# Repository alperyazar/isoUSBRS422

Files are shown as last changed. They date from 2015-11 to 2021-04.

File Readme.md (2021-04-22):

# isoUSBRS422

Links:

| | |
| --- |---|
| Up-to-date BOM (with price) | [https://octopart.com/bom-tool/p8YATXJo](https://octopart.com/bom-tool/p8YATXJo) |
| Known Issues | [https://github.com/alperyazar/isoUSBRS422/issues](https://github.com/alperyazar/isoUSBRS422/issues)
| Photo Gallery | [https://www.flickr.com/photos/134583834@N07/sets/72157658466808770/](https://www.flickr.com/photos/134583834@N07/sets/72157658466808770/) |
| Hackaday.io | [https://hackaday.io/project/3943-isousbrs422](https://hackaday.io/project/3943-isousbrs422) |
| Project Page on My Website (may contain additional materials) | [https://www.ayazar.com/projects/isousbrs422.html](https://www.ayazar.com/projects/isousbrs422.html) |

> :information_source: isoUSBRS422v1 is on **EEVblog Mailbag** and **Dangerous Prototypes.** See [On The Web](#on-the-web) section at the bottom for details.

isoUSBRS422 is an **isolated** USB <-> RS422/RS485 converter board (~5x5 cm). It should work with Windows, Linux and MacOSX (not fully tested for all operating systems by me).

**THIS PROJECT IS PUBLISHED UNDER CC BY-NC-SA 4.0 LICENSE**

**AS IS, ABSOLUTELY NO WARRANTY**

## Features

Here is the summary of features in “catalog” style:

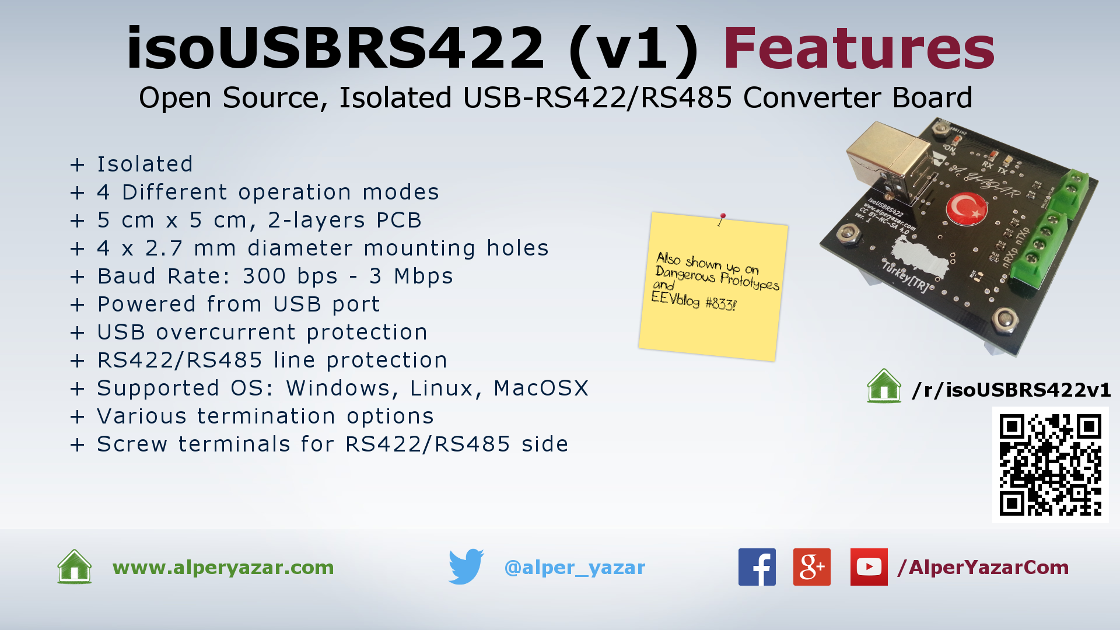
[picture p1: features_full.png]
Summary of isoUSBRS422 features


*Summary of isoUSBRS422 features*

Here is the introduction video:

Part 1 - Features | isoUSBRS422v1 (with Subtitles) (http://www.youtube.com/watch?v=jb3v3Kmv85k "Part 1 - Features | isoUSBRS422v1 (with Subtitles)")

* **Isolated** 5000 Vrms (IC specification, not tested by me)
* **4 different modes** RS-422, RS-485 4-wire, RS-485 2-wire, RS-485 2-wire w/echo suppression
* **5 cm x 5 cm, 2-layers PCB**
* **4 x 2.7 mm diameter mounting holes** Electrically floating
* **Baud Rate: 300 bps - 3 Mbps** Baud Rate = 3000000 / (n + x) where ‘n’ can be any integer between 2 and 16,384 and ‘x’ can be a sub-integer of the value 0, 0.125, 0.25, 0.375, 0.5, 0.625, 0.75, or 0.875. When n = 1, x = 0, i.e. baud rate divisors with values between 1 and 2 are not possible.
* **Powered from USB port** No external power supply is required. 5V from USB port is sufficient to operate the device.
* **USB overcurrent protection** Yes, by a polyfuse
* **RS-422/RS-485 line protection** Yes, it should meet IEC 61000-4-2, 61000-4-4 and IEC 61000-4-5 (IC specification, not tested by me)
* Supported OS: **Windows, Linux, MacOSX**
* **Various termination options** Different termination topologies can be selected by changing some passives on the component side using solder and iron! (Sorry, no dip switches)
* **Screw terminals for RS-422/RS-485 side**
* **LED indicators: Power, Transmit, Receive**

## What is isoUSBRS422?

As I said, basically it is an USB ↔ RS-422/RS-485 converter board. It can be used to communicate devices with RS-422/RS-485 interface by using a USB port of PC. Also, ground of USB port is isolated from ground of RS-422/RS-485 channel. It may help you to prevent [ground loops](https://en.wikipedia.org/wiki/Ground_loop_%28electricity%29) in large systems. See [Galvanic isolation](https://en.wikipedia.org/wiki/Galvanic_isolation) for further explanation. I will explain technical details later.

isoUSBRs422 is my first open source hardware and also KiCad experience. I did some boards for my daily job previously, but I never published them in public domain. So, I decided to do "something" to gain experience about open source publishing and low cost PCB production. Here there are some photos:

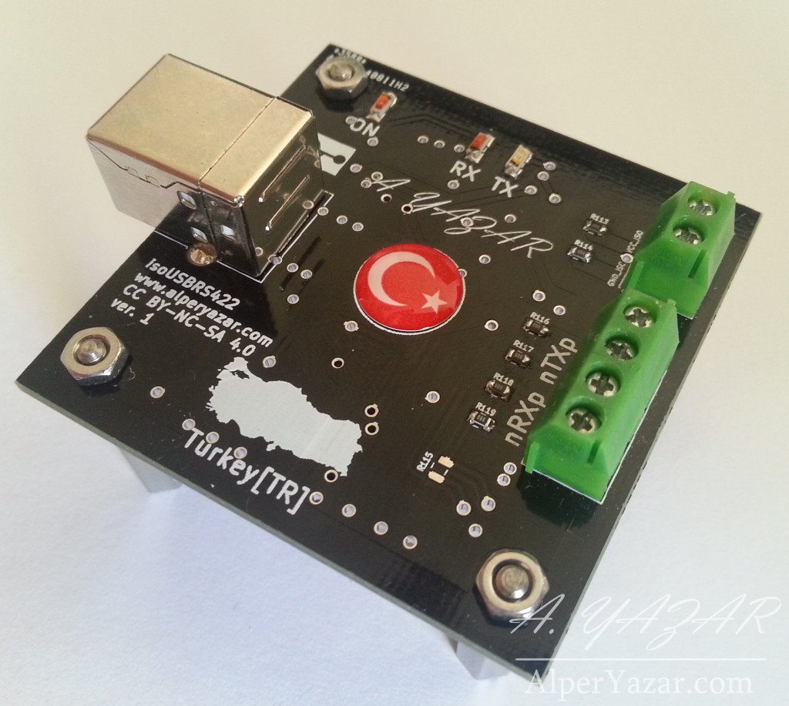
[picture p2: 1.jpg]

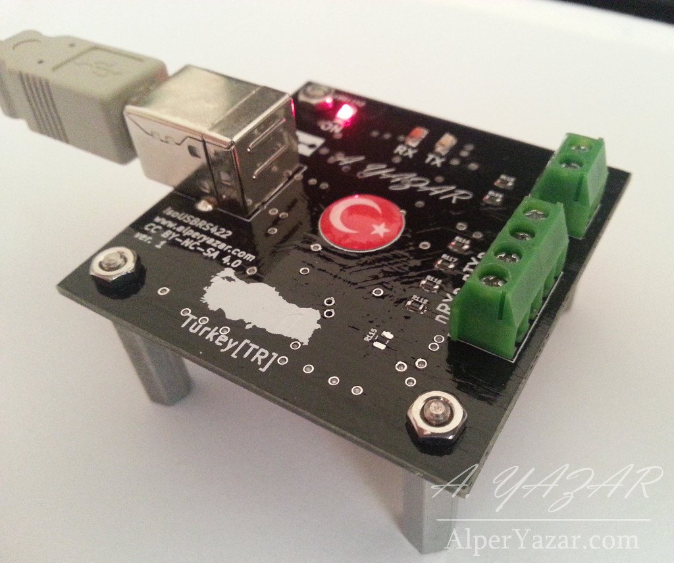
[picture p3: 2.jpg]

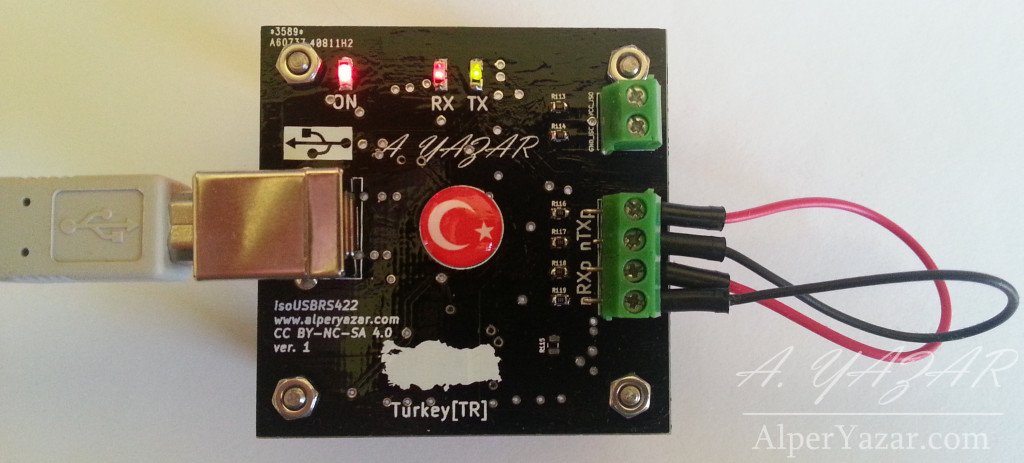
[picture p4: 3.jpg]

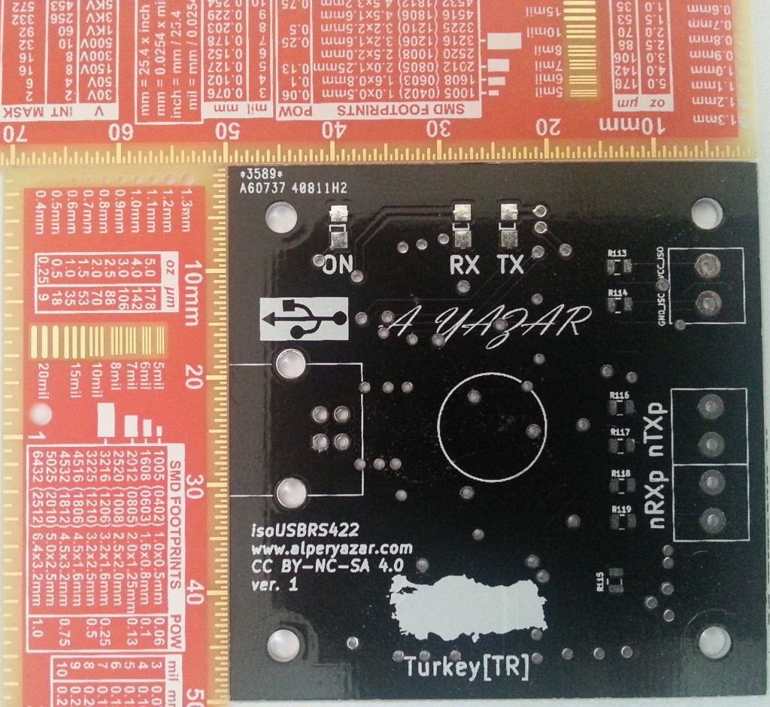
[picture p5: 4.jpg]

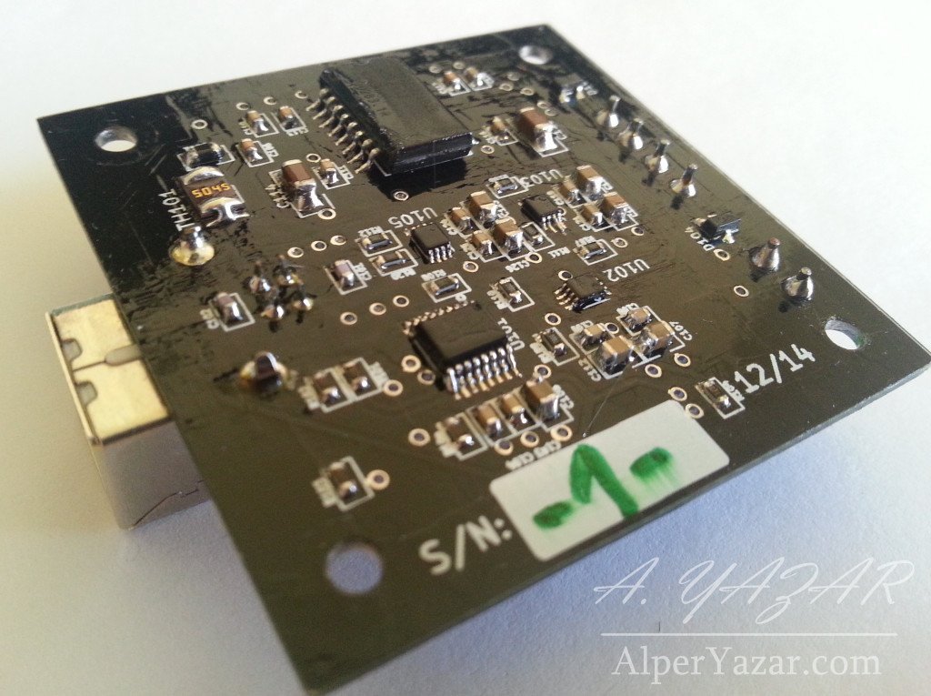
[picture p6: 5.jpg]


## Why

### Why did I design an isolated USB ↔ RS-422/RS-485 converter board?

As I explained previously, I wanted to design and publish "something". I use USB ↔ RS-422 converter devices for my daily job heavily. I checked PCB manufacturers and decided to try Dirtypcbs. Dimension limit for the cheapest option is 5 cm x 5 cm and I decided to stick to this limit. I thought that I can design an isolated USB <-> RS-422 converter board within in this size limit and use it for my daily job. So I did it.

### Why did I chose the name isoUSBRS422? Does this board support RS-485 in addition to RS-422, right?

Yes, it supports both protocols. My initial goal was designing an isolated USB ↔ RS-422 converter board. Because I use RS-422 mainly not RS-485. However after design I noticed that it can also be used as an RS-485 converter. Also a name like *isoUSBRS422-485* is quite long for a board name.

### Why did I use KiCad?

Couple of years ago, I designed 3 different boards for my project design course in collage using DipTrace. DipTrace is great and I would continue to use it if I didn’t decide to publish my project and make it open source. DipTrace has *freeware* version for non-commercial users. However, this version has limitation on number of total pins on a single PCB. I think that software used for an open source project should be free (as in beer and freedom) as much as possible. Also, I had to create some parts in library for this project. If I use DipTrace, later I may hit the pin limit for my other projects and I have to move another software. For these reasons, I eliminate Eagle. I think that, it is easier to learn and use DipTrace than Eagle.

From *free* PCB design softwares, I tried gEDA and KiCad. I encountered some stability issues in gEDA then I selected to use KiCad. This is my first KiCad and experience and now I am happy with my decision. I recommend KiCad. It has quite good documentation and there are great videos on YouTube explaining almost all aspects of the software. Also there are active helping forums on the internet.

### Why the heck did I select a USB chip from FTDI? Don’t I know that they did stupid things in the past? Am I supporting them?

Yes, I know and I am not an FTDI fanboy. For those who don’t know the subject:

EEVblog #676 - RANT: FTDI Bricking Counterfeit Chips! (http://www.youtube.com/watch?v=eU66as4Bbds "EEVblog #676 - RANT: FTDI Bricking Counterfeit Chips!")

and

[http://hackaday.com/2014/10/22/watch-that-windows-update-ftdi-drivers-are-killing-fake-chips/](http://hackaday.com/2014/10/22/watch-that-windows-update-ftdi-drivers-are-killing-fake-chips/)

started to desing and selected to components prior to FTDI thing. I learned the issue in the beginning of the layout. I was very excited to finish my board and decided to finish it. So, that’s the story. Now, I can’t proudly say that “Hey, I am using an FTDI chip on my board”. I know that, many of hackers and makers encountered problems due to stupidity of this company. Since this is an open source project and aims makers especially, I am not very happy with this chip. But this is the case.

## Do It Yourself (DIY)



> :warning: AS IS, ABSOLUTELY NO WARRANTY. TAKE YOUR OWN RISK

Your read the features list and are fascinated about the project (LOL). You look forward to make your own isoUSBRS422 board and use it in your projects. Here is the good new: This is an open source project and you can make your own copy for non-commercial purposes!

> :information_source: This project is published under CC BY-NC-SA 4.0 license. It means that you can make your own copy for non-commercial purposes. Even, you can modify the project files, ex. PCB, if you refer to this original work properly and redistribute your version with the same license. See [https://creativecommons.org/licenses/by-nc-sa/4.0/](https://creativecommons.org/licenses/by-nc-sa/4.0/) for further details. Contact if you have any questions.

> :information_source: As I said in videos (see below), I may have some extra PCBs or even components in my hand. I may able to send you if you REALLY want to make your own board, free of charge. Please contact if you are interested in.

## Video Tutorials

I prepared 6 tutorial videos with total runtime ~1.5 hours (!) for makers. Below, videos are given in order. Click images to watch the videos. Also you can find a ordered playlist here: [https://www.youtube.com/watch?v=EZh2zi6m1yI&list=PLr5LL6z9GIeGnNSeiEEnGr73dqn5cAOdi](https://www.youtube.com/watch?v=EZh2zi6m1yI&list=PLr5LL6z9GIeGnNSeiEEnGr73dqn5cAOdi)

### Part 0 - Introduction

Part 0 - Introduction | isoUSBRS422v1 (with Subtitles) (http://www.youtube.com/watch?v=EZh2zi6m1yI "Part 0 - Introduction | isoUSBRS422v1 (with Subtitles)")

*Click on the image to watch the video*

### Part 1 - Features

Part 1 - Features | isoUSBRS422v1 (with Subtitles) (http://www.youtube.com/watch?v=jb3v3Kmv85k "Part 1 - Features | isoUSBRS422v1 (with Subtitles)")

*Click on the image to watch the video*

### Part 2 - Project Files

Part 2 - Project Files | isoUSBRS422v1 (with Subtitles) (http://www.youtube.com/watch?v=QmU2l9yxdq4 "Part 2 - Project Files | isoUSBRS422v1 (with Subtitles)")

*Click on the image to watch the video*

### Part 3 - Board Production

Part 3 - Board Production| isoUSBRS422v1 (with Subtitles) (http://www.youtube.com/watch?v=mPhScHU1XKU "Part 3 - Board Production| isoUSBRS422v1 (with Subtitles)")

*Click on the image to watch the video*

### Part 4 - Driver Installation, Programming, Functional Verification

Part 4 - Driver Installation, Programming, Functional Verification | isoUSBRS422v1 (with Subtitles) (http://www.youtube.com/watch?v=gxzl12bP4j4 "Part 4 - Driver Installation, Programming, Functional Verification | isoUSBRS422v1 (with Subtitles)")

*Click on the image to watch the video*

### Part 5 - Operation Modes

Part 5 - Operation Modes | isoUSBRS422v1 (with Subtitles) (http://www.youtube.com/watch?v=e4YLkROiQLc "Part 5 - Operation Modes | isoUSBRS422v1 (with Subtitles)")

*Click on the image to watch the video*

### Part 6 - Known Issues

Part 6 - Known Issues | isoUSBRS422v1 (with Subtitles) (http://www.youtube.com/watch?v=GGQSbGbkveA "Part 6 - Known Issues | isoUSBRS422v1 (with Subtitles)")

*Click on the image to watch the video*

## On The Web

isoUSBRS422 project is also shown up on some websites.

### Dangerous Prototypes

[Blog post of Dangerous Prototypes about isoUSBRS422 project](http://dangerousprototypes.com/2015/12/17/isousbrs422-an-open-source-isolated-usb-rs422rs485-converter-board/)

### EEVblog

isoUSBRS422 on EEVblog #833 - Mailbag (https://www.youtube.com/watch?time_continue=822&v=dXbbJOH59oo "isoUSBRS422 on EEVblog #833 - Mailbag")

*Click on the image to watch the video*

isoUSBRS422v1 board is shown up in [EEVblog #833 - Mailbag](https://www.youtube.com/watch?time_continue=822&v=dXbbJOH59oo) episode between **13:42 - 18:26**.

## Folder Structure

* `BOM` Contains bill of materials of board

* `Driver` Contains necessary drivers. Online Windows 7 (and probably newest versions) should install driver automatically. If you are running on an offline machine you may use drivers at that folder. However, I strongly recommend to get the newest driver from USB chip vendor website: [http://www.ftdichip.com/Drivers/VCP.htm](http://www.ftdichip.com/Drivers/VCP.htm) I won't update drivers at that folder when FTDI publishes new drivers. They are latest drivers at that time.

* `Firmware` Contains profile file for utility called FT_Prog (contains in Utility folder). Once you finish isoUSBRS422 board, FT230x will not work as RS422/RS485 converter. This chip should be programmed only once. You may use the given profiles for proper operation.

* `Gerber` Contains Gerber files for PCB production. You may produce exactly same board as mine using these files.

* `KiCad` Contains KiCad project files. My KiCad version is (2013-07-07 BZR 4022)-stable. You should able to open project files and edit according to your needs (please consider license).

* `PCB` Contains ZofzPCB (see: [https://www.ayazar.com/log/2014/12/zofzpcb.html](https://www.ayazar.com/log/2014/12/zofzpcb.html)) rendered board file and some computer generated images of PCB.

* `Schematic` Contains PDF of schematic.

* `Utility` Some programs to program isoUSBRS422 board an test it.

*You are always welcomed to contact me.*

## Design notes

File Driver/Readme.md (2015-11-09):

# Drivers

I **strongly recommend** you to install the most up-to-date drivers from the USB chip vendor site if you have an internet connection.

http://www.ftdichip.com/Drivers/VCP.htm

Also please visit same site for missing ones.

*15461*

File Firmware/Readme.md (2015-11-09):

# Firmware
These are the necessary firmwares for board for different modes. These files are used by FT_Prog found in the Utility folder. 

* *isoUSBRS422_v1_default.xml*	This is the read configuration from new chip. Given as reference. **Should not be used for production.**
* *isoUSBRS422_v1_RS422.xml* 	RS422 operation. Transmitter and receiver are always enabled. It is suitable for multi-point topology. It is also good for loopback testing. 
* *isoUSBRS422_v1_RS485.xml* 	4-wire and 2-wire RS485. Receiver is always enabled. Transmitter is enabled when there is a transmission otherwise it is in high-z state. It is suitable for multi-drop topology.
* *isoUSBRS422_v1_RS485_sE.xml* 2-wire RS485 with echo suppression. Transmitter works same as the RS485 mode, it is enabled when there is transmission only. Additionally, receiver is disabled when there is a transmission. It is useful to suppress echo during transmission for 2-wire RS485 connection. It is impossible to do a loopback test with this mode.

*15461*

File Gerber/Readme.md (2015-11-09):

# Gerber

* *isoUSBRS422.txt* 			Drill file (Excellon format)
* *isoUSBRS422-F_SilkS.gto* 	Component Side - Silkscreen
* *isoUSBRS422-F_Mask.gts* 		Component Side - Solder Mask
* *isoUSBRS422-F_Cu.gtl* 		Component Side - Copper
* *isoUSBRS422-B_Cu.gbl* 		Solder Side - Copper
* *isoUSBRS422-B_Mask.gbs* 		Solder Side - Solder Mask
* *isoUSBRS422-B_SilkS.gbo* 	Solder Side - Silkscreen
* *isoUSBRS422-Edge_Cuts.gbr* 	Board Edges

*1520*

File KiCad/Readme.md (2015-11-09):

# KiCad

Tested KiCad Version: (2013-07-07 BZR 4022)-stable on Windows 7 SP1

*1544*

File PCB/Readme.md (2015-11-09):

# PCB

Tested ZofzPCB (3D Gerber View) Version: 0.5.0002 on Windows 7 SP1 and XP SP3

www.zofzpcb.com

*1544*

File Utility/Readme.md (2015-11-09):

# Utility

* *FT_Prog_v3.0.56.245*	Used to program an isoUSBRS422 board using settings given in Firmware folder.
* *WinSSD*	Can be used to apply more advanced tests than simple loopback like BERT.

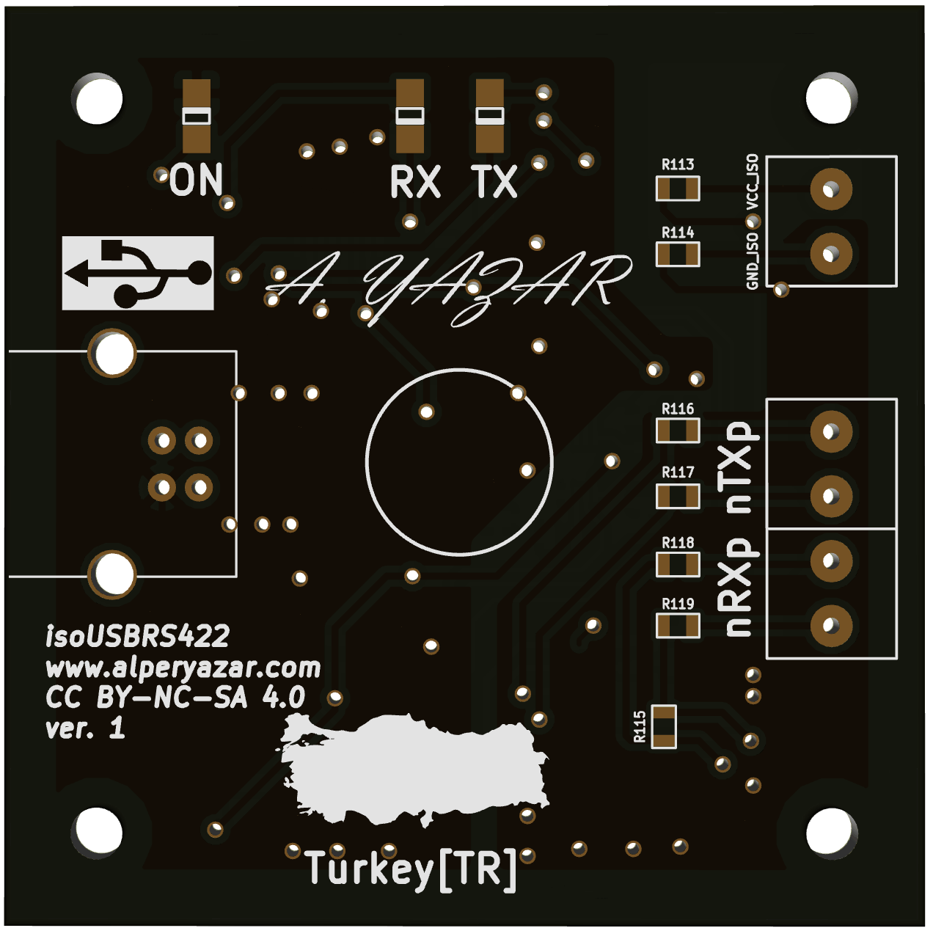
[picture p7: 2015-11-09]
PCB/isoUSBRS422_cs.png

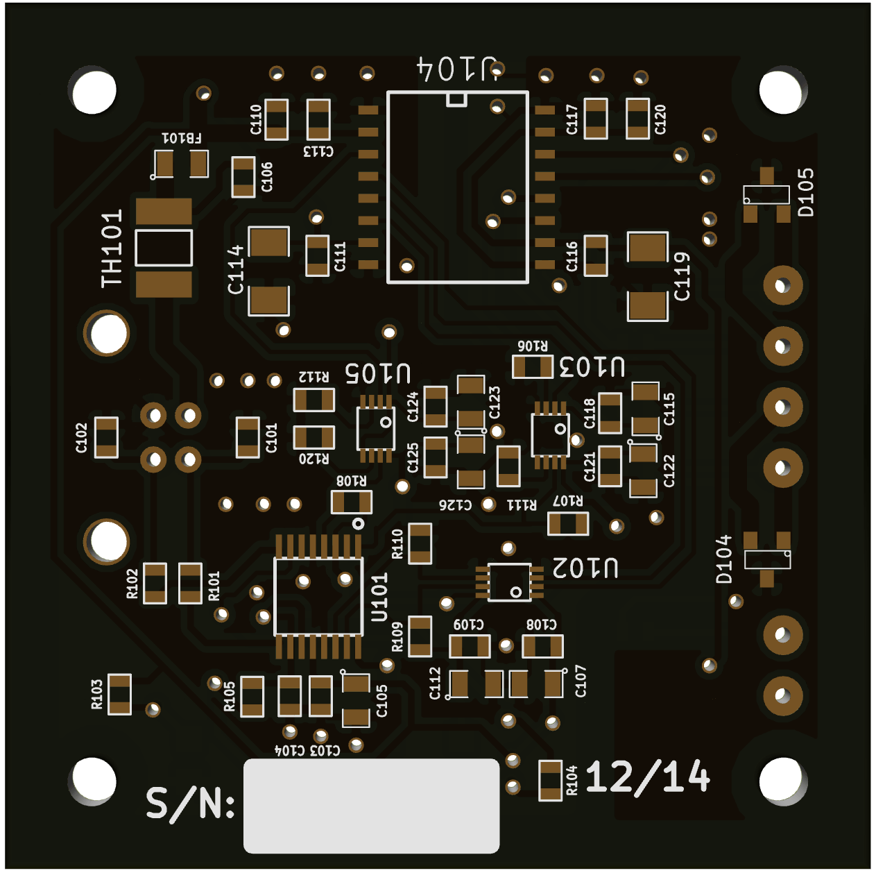
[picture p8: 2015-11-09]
PCB/isoUSBRS422_ss.png

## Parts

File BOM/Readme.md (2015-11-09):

# BOM (Bill of Materials)

All components are listed in **isoUSBRS422_BOM.txt** file by reference and value seperately.

When I soldered boards for testing, I used passive components that are available for me. I recommend X5R or X7R ceramic capacitors. Film resistors with 1% tolerance should be fine.  

For all components, please see **isoUSBRS422_BOM_v1.pdf** or **isoUSBRS422_BOM_v1.xlsx** files. For up-to-date price and BOM information, please visit http://www.alperyazar.com/r/isoUSBRS422BOMv1

*15386*

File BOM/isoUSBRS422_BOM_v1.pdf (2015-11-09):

Qty | Line Item | Manufacturer | MPN | Schematic Reference | Description
2 | PSM712LFT7 | Protek Devices | PSM712-LF-T7 | D104 D105
1 | MI0805K601R-10 | Laird | MI0805K601R-10 | FB101
1 | MF-MSMF050-2 | Bourns | MF-MSMF050-2 | TH101
1 | FT230XS-R | FTDI | FT230XS-R | U101
3 | SN74LVC2T45DCUR | Texas Instruments | SN74LVC2T45DCUR | U102 U103 U105
1 | ADM2682EBRIZ | Analog Devices | ADM2682EBRIZ | U104
7 | 0805YC475KAT2A | AVX | 0805YC475KAT2A | C105 C107 C112 C115 C122 C123 C126 | Alternatives with the same capacitance and package size may be used. Not so critical.
3 | C0603C103K5RACTU | Kemet | C0603C103K5RACTU | C106 C113 C117 | Alternatives with the same capacitance and package size may be used. Not so critical.
2 | C0603C470J5GACTU | Kemet | C0603C470J5GACTU | C101 C102 | Alternatives with the same capacitance and package size may be used. Not so critical.
2 | 1206YC106KAT2A | AVX | 1206YC106KAT2A | C114 C119 | Alternatives with the same capacitance and package size may be used. Not so critical.
12 | C0603C104K4RACTU | Kemet | C0603C104K4RACTU | C103 C104 C108 C109 C110 C111 C116 C118 C120 C121 C124 C125 | Alternatives with the same capacitance and package size may be used. Not so critical.
1 | ADA724 | Adafruit Industries | ADA724 | J102 J103 J104 | Just randomly chosen 3.5mm pitch 2 pin screw terminals.
1 | 61400416121 | Würth Elektronik | 61400416121 | J101 | Just randomly chosen an USB Type-B connector.
6 | CR0603-J/-000ELF | Bourns | CR0603-J/-000ELF | R113 R114 R116 R117 R118 R119 | Just randomly choosen 0 ohms. You may even make a solder bridge insted of a resistor!
2 | CR0603-FX-27R0ELF | Bourns | CR0603-FX-27R0ELF | R101 R102 | Alternatives with the same resistance, tolerance and package size may be used.
1 | CR0603-FX-1210ELF | Bourns | CR0603-FX-1210ELF | R115 | THERE IS A PROBLEM WITH THIS RESISTOR. SEE "KNOWN PROBLEMS". Alternatives with the same resistance, tolerance and package size may be used.

This (http://www.alperyazar.com/r/isoUSBRS422BOMv1) BOM is generated using Octopart. Please visit for up-to-date component prices and materials:http://www.alperyazar.com/r/isoUSBRS422BOMv1Generated @ 15386

2 | CR0603-FX-2700GLF | Bourns | CR0603-FX-2700GLF | R104 R105 | Alternatives with the same resistance, tolerance and package size may be used.
1 | CR0603-FX-3300GLF | Bourns | CR0603-FX-3300GLF | R103 | Alternatives with the same resistance, tolerance and package size may be used.
8 | CR0603-FX-1002GLF | Bourns | CR0603-FX-1002GLF | R106 R107 R108 R109 R110 R111 R112 R120 | Alternatives with the same resistance, tolerance and package size may be used.
2 | HSMS-C680 | Avago | HSMS-C680 | D101 D103 | Actually, I used LED from another brand but it is hard to find the same part on the market. Therefore, you should be able to use this LED without having so much trouble. However, I didn't verify this part.
1 | HSMG-C680 | Avago | HSMG-C680 | D102 | Actually, I used LED from another brand but it is hard to find the same part on the market. Therefore, you should be able to use this LED without having so much trouble. However, I didn't verify this part.

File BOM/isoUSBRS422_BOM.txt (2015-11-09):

eeschema (2013-07-07 BZR 4022)-stable  >> Creation date: 11.05.2015 22:11:10
#Cmp ( order = Reference )
| C101       47 pF       ; SM0603      
| C102       47 pF       ; SM0603      
| C103       100 nF      ; SM0603      
| C104       100 nF      ; SM0603      
| C105       4.7 uF      ; SM0805      
| C106       10 nF       ; SM0603      
| C107       4.7 uF      ; SM0805      
| C108       100 nF      ; SM0603      
| C109       100 nF      ; SM0603      
| C110       100 nF      ; SM0603      
| C111       100 nF      ; SM0603      
| C112       4.7 uF      ; SM0805      
| C113       10 nF       ; SM0603      
| C114       10 uF       ; SM1206      
| C115       4.7 uF      ; SM0805      
| C116       100 nF      ; SM0603      
| C117       10 nF       ; SM0603      
| C118       100 nF      ; SM0603      
| C119       10 uF       ; SM1206      
| C120       100 nF      ; SM0603      
| C121       100 nF      ; SM0603      
| C122       4.7 uF      ; SM0805      
| C123       4.7 uF      ; SM0805      
| C124       100 nF      ; SM0603      
| C125       100 nF      ; SM0603      
| C126       4.7 uF      ; SM0805      
| D101       LED_PWR     ; CR_10_LED   
| D102       LED_TX      ; CR_10_LED   
| D103       LED_RX      ; CR_10_LED   
| D104       PSM712LFT7  ; SOT23       
| D105       PSM712LFT7  ; SOT23       
| FB101      MI0805K601R-10; SM0805      
| J101       USB         ; USB_B       
| J102       KLE3MM5     ; KLE3mm5     
| J103       KLE3MM5     ; KLE3mm5     
| J104       KLE3MM5     ; KLE3mm5     
| R101       27          ; SM0603      
| R102       27          ; SM0603      
| R103       330         ; SM0603      
| R104       270         ; SM0603      
| R105       270         ; SM0603      
| R106       10k         ; SM0603      
| R107       10k         ; SM0603      
| R108       10k         ; SM0603      
| R109       10k         ; SM0603      
| R110       10k         ; SM0603      
| R111       10k         ; SM0603      
| R112       10k         ; SM0603      
| R113       0           ; SM0603      
| R114       0           ; SM0603      
| R115       121         ; SM0603      
| R116       0           ; SM0603      
| R117       0           ; SM0603      
| R118       0           ; SM0603      
| R119       0           ; SM0603      
| R120       10k         ; SM0603      
| TH101      MF-MSMF050-2; MS_MSMF_Style_1
| U101       FT230X      ; SSOP16      
| U102       SN74LVC2T45 ; R_PDSO_G8   
| U103       SN74LVC2T45 ; R_PDSO_G8   
| U104       ADM2682E    ; SO16W       
| U105       SN74LVC2T45 ; R_PDSO_G8   
#End Cmp

#Cmp ( order = Value )
| 4.7 uF       C105      ; SM0805      
| 4.7 uF       C107      ; SM0805      
| 4.7 uF       C112      ; SM0805      
| 4.7 uF       C115      ; SM0805      
| 4.7 uF       C122      ; SM0805      
| 4.7 uF       C123      ; SM0805      
| 4.7 uF       C126      ; SM0805      
| 47 pF        C101      ; SM0603      
| 47 pF        C102      ; SM0603      
| 100 nF       C103      ; SM0603      
| 100 nF       C104      ; SM0603      
| 10 nF        C106      ; SM0603      
| 100 nF       C108      ; SM0603      
| 100 nF       C109      ; SM0603      
| 100 nF       C110      ; SM0603      
| 100 nF       C111      ; SM0603      
| 10 nF        C113      ; SM0603      
| 100 nF       C116      ; SM0603      
| 10 nF        C117      ; SM0603      
| 100 nF       C118      ; SM0603      
| 100 nF       C120      ; SM0603      
| 100 nF       C121      ; SM0603      
| 100 nF       C124      ; SM0603      
| 100 nF       C125      ; SM0603      
| 10 uF        C114      ; SM1206      
| 10 uF        C119      ; SM1206      
| LED_PWR      D101      ; CR_10_LED   
| LED_TX       D102      ; CR_10_LED   
| LED_RX       D103      ; CR_10_LED   
| PSM712LFT7   D104      ; SOT23       
| PSM712LFT7   D105      ; SOT23       
| MI0805K601R-10 FB101     ; SM0805      
| KLE3MM5      J102      ; KLE3mm5     
| KLE3MM5      J103      ; KLE3mm5     
| KLE3MM5      J104      ; KLE3mm5     
| USB          J101      ; USB_B       
| 0            R113      ; SM0603      
| 0            R114      ; SM0603      
| 0            R116      ; SM0603      
| 0            R117      ; SM0603      
| 0            R118      ; SM0603      
| 0            R119      ; SM0603      
| 27           R101      ; SM0603      
| 27           R102      ; SM0603      
| 121          R115      ; SM0603      
| 270          R104      ; SM0603      
| 270          R105      ; SM0603      
| 330          R103      ; SM0603      
| 10k          R106      ; SM0603      
| 10k          R107      ; SM0603      
| 10k          R108      ; SM0603      
| 10k          R109      ; SM0603      
| 10k          R110      ; SM0603      
| 10k          R111      ; SM0603      
| 10k          R112      ; SM0603      
| 10k          R120      ; SM0603      
| MF-MSMF050-2 TH101     ; MS_MSMF_Style_1
| SN74LVC2T45  U102      ; R_PDSO_G8   
| SN74LVC2T45  U103      ; R_PDSO_G8   
| SN74LVC2T45  U105      ; R_PDSO_G8   
| ADM2682E     U104      ; SO16W       
| FT230X       U101      ; SSOP16      
#End Cmp

#End List

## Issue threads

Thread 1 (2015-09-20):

Improper Termination Resistor Package Size

alperyazar, 2015-09-20:
RS422 termination resistor, R115, may have a problem. I used 0603 package for this resistor inadvertently. Power dissipation of 0603 package is usually limited to 63 mW or 100 mW. This can cause problem since the RS422/RS485 device at the other side may drive the isoUSBRS422 board to dissipate heat more than the rated power.

alperyazar, 2015-11-10:
R115 may not be needed if length of the RS422/RS485 bus and communication speed are suitable together. One can be read this: http://www.ti.com/lit/an/slla070d/slla070d.pdf

If termination is required and 0603 package resistor isn't suitable, an axial resistor can be placed pins between *nRXp* screw terminal with bus cable. Not an elegant but it is a working solution.

Closed 2020-10-26.

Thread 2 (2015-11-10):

Vbus capacitance exceeds the maximum allowable limit given in the USB 2.0 specification.

alperyazar, 2015-11-10:
The maximum Vbus capacitance is given as 10 uF in "7.2.4.1 Inrush Current Limiting" USB 2.0 specification. Even if C114 + C107 > 10 uF, for example. As far as I understand, maximum capacitance limit is related with inrush current. If host can handle with this inrush current,it is OK. The specification says that drop on Vbus should be smaller than 330 mV. Your PC or hub should provide this.

I tested isoUSBRS422_v1 boards using several desktop and laptop computers and didn't observe any problem.

Also TH101 and FB101 _may_ help to decrease inrush current little. I think, a real current and voltage measurement will help much more than this hypothetical discussion.

As a summary, be aware that there may be some problems related with inrush current.

Closed 2020-10-26.

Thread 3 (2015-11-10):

Two vias are close to USB connector.

alperyazar, 2015-11-10:
Two vias are close to chassis of USB connector. Chassis of connector is left floating  and both vias are on the same net. Both of them are GND. Considering tolerances, a connector may touch, especially to the bottom one. In that case, chassis of connector will be GND. Still, this may not cause any problem.But, it is better to prevent making a large, exposed metal GND of USB side. None of my two isoUSBRS422 boards has this problem.

In the future, soldermask may be applied on vias. In a better way, two vias may be moved.

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

Closed 2020-10-26.

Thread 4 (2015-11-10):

Are you using chip from FTDI?

alperyazar, 2015-11-10:
Yes, I know and I am not an FTDI fanboy. For those who don't know the subject:

https://www.youtube.com/watch?v=eU66as4Bbds

http://hackaday.com/2014/10/22/watch-that-windows-update-ftdi-drivers-are-killing-fake-chips/

I started to desing and selected to components prior to FTDI thing. I learned the issue in the beginning of the layout. I was very excited to finish my board and decided to finish it. So, that's the story. Now, I can't proudly say that "Hey, I am using an FTDI chip on my board". I know that, many of hackers and makers encountered problems due to stupidity of this company. Since this is an open source project and aims makers especially, I am not very happy with this chip. But this is the case.

alperyazar, 2015-11-10:
USB chip can be changed in the next design if there will be any.

Closed 2020-10-26.

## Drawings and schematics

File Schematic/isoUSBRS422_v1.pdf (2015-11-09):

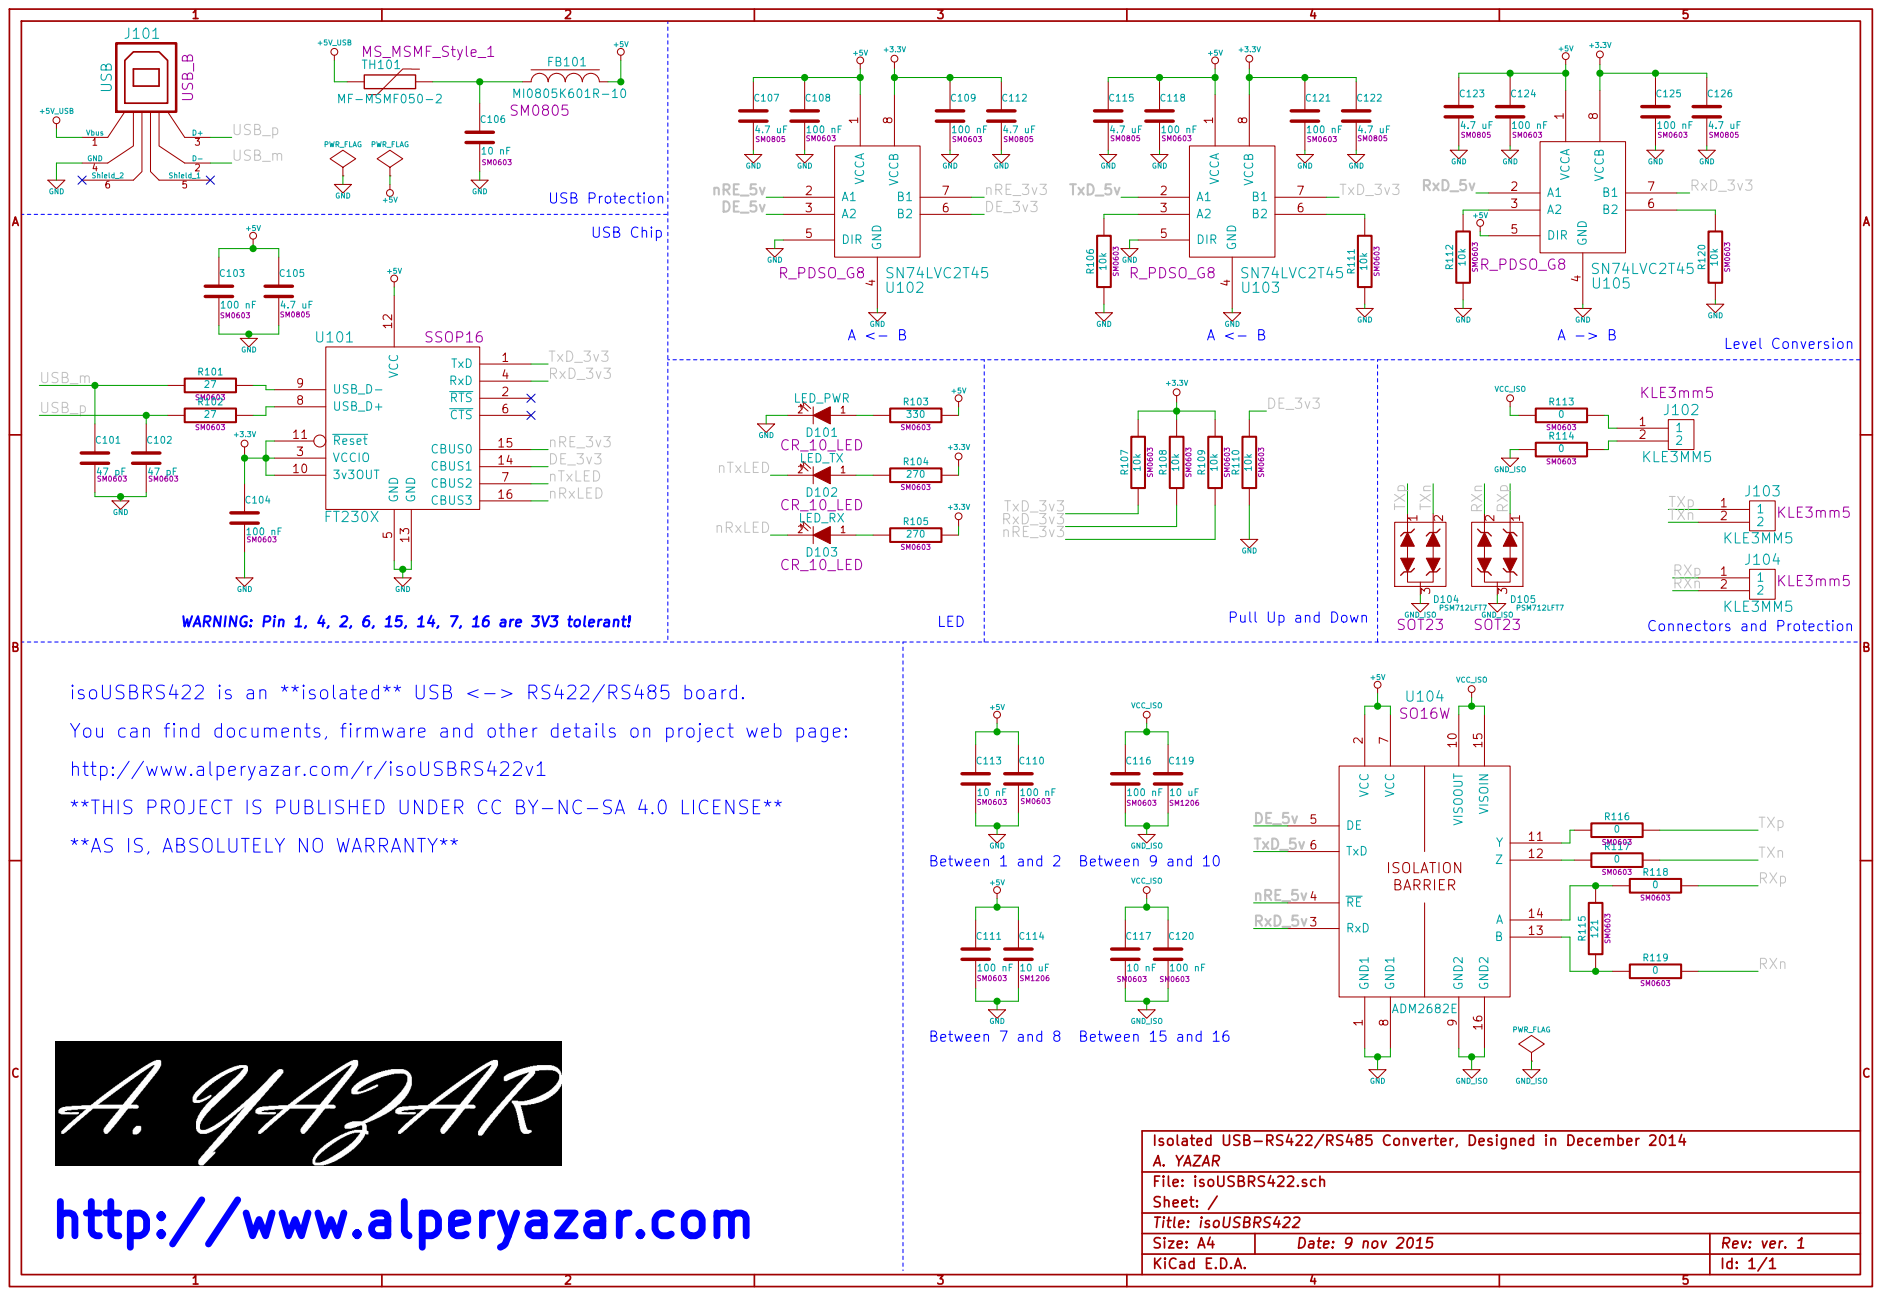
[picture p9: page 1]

isoUSBRS422 is an **isolated** USB <-> RS422/RS485 board.
You can find documents, firmware and other details on project web page:
http://www.alperyazar.com/r/isoUSBRS422v1
**THIS PROJECT IS PUBLISHED UNDER CC BY-NC-SA 4.0 LICENSE**
**AS IS, ABSOLUTELY NO WARRANTY**

2 RxD 3 RE 4 DE 5 TxD 6 VCC

Isolated USB-RS422/RS485 Converter, Designed in December 2014
Sheet: / A. YAZAR
File: isoUSBRS422.sch

http://www.alperyazar.com

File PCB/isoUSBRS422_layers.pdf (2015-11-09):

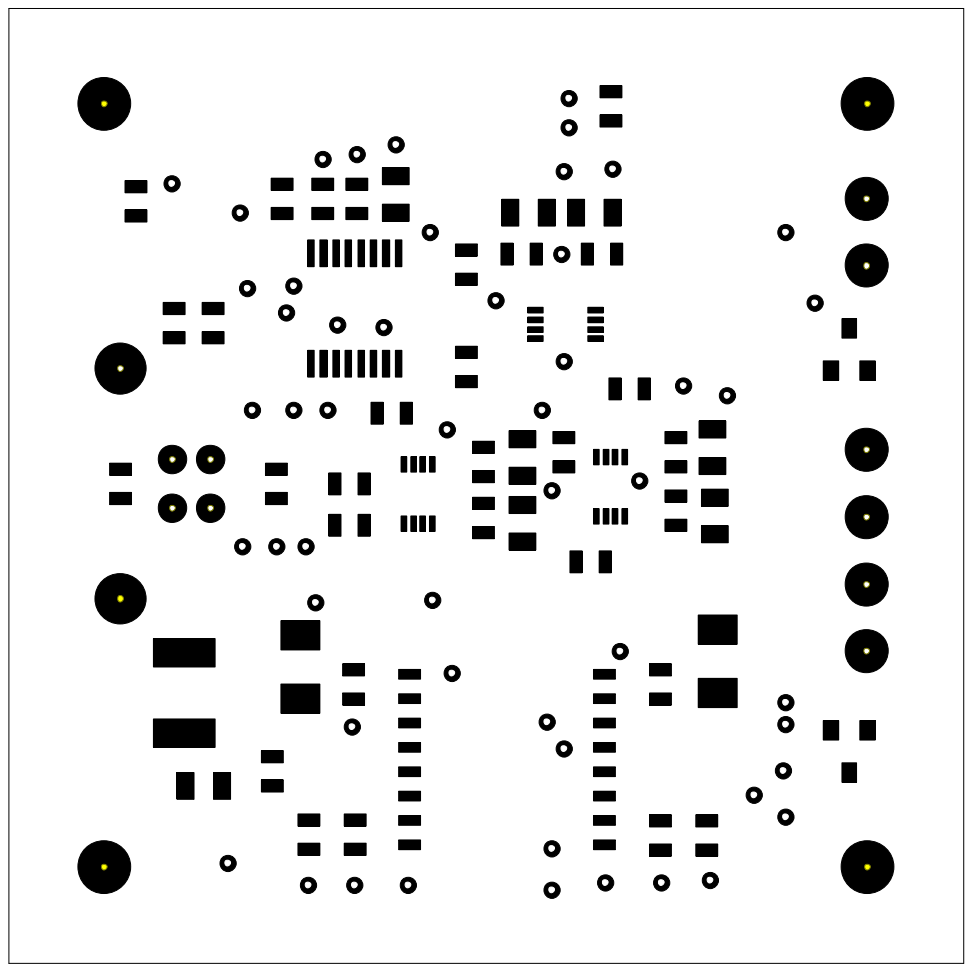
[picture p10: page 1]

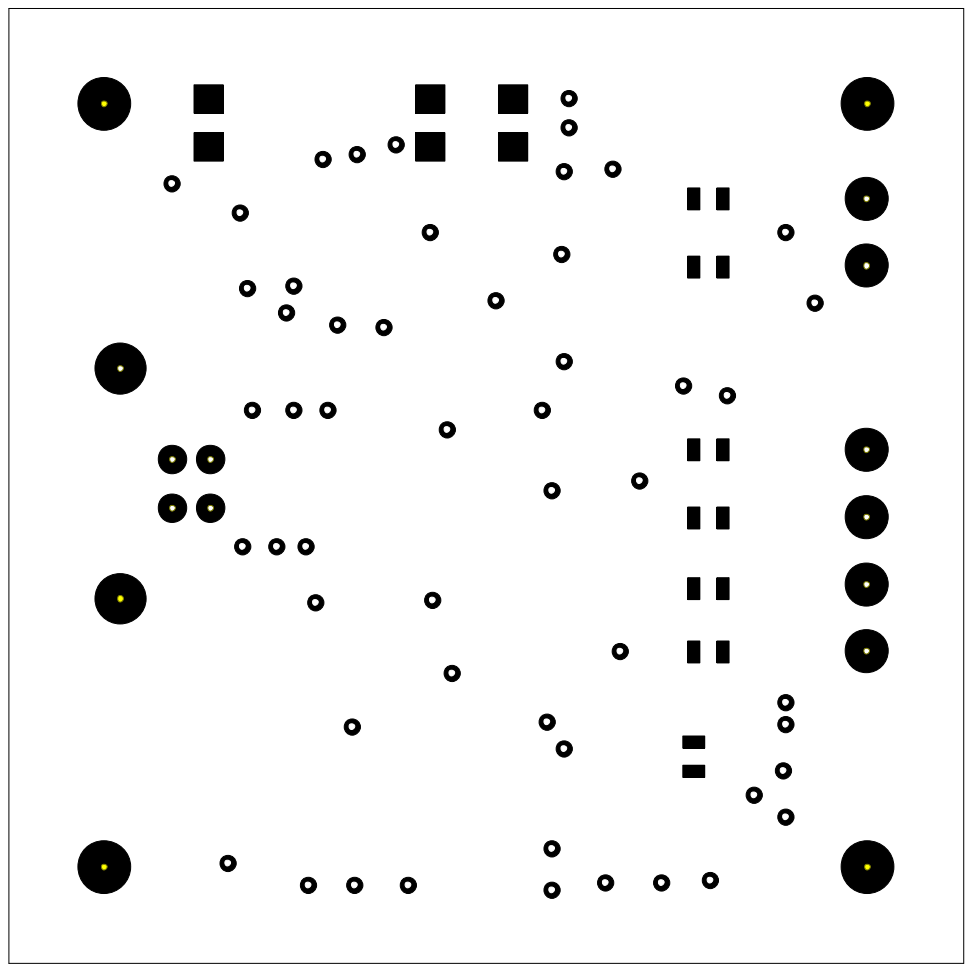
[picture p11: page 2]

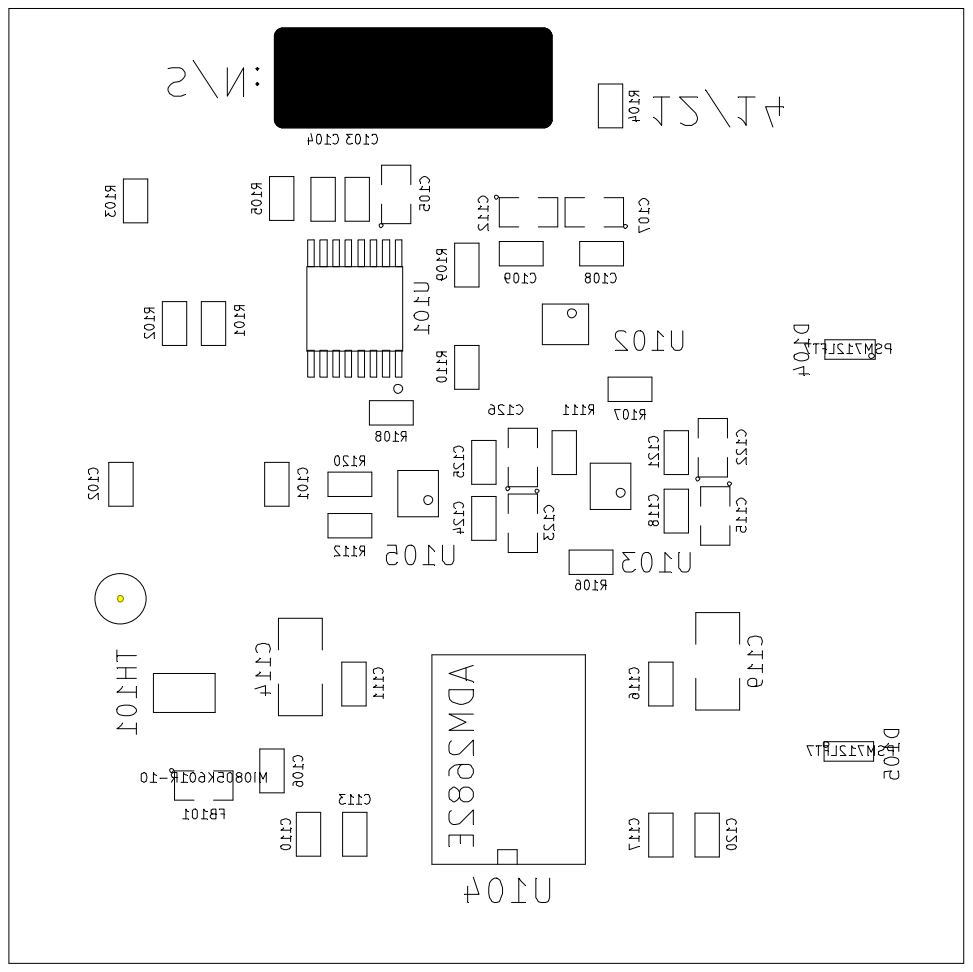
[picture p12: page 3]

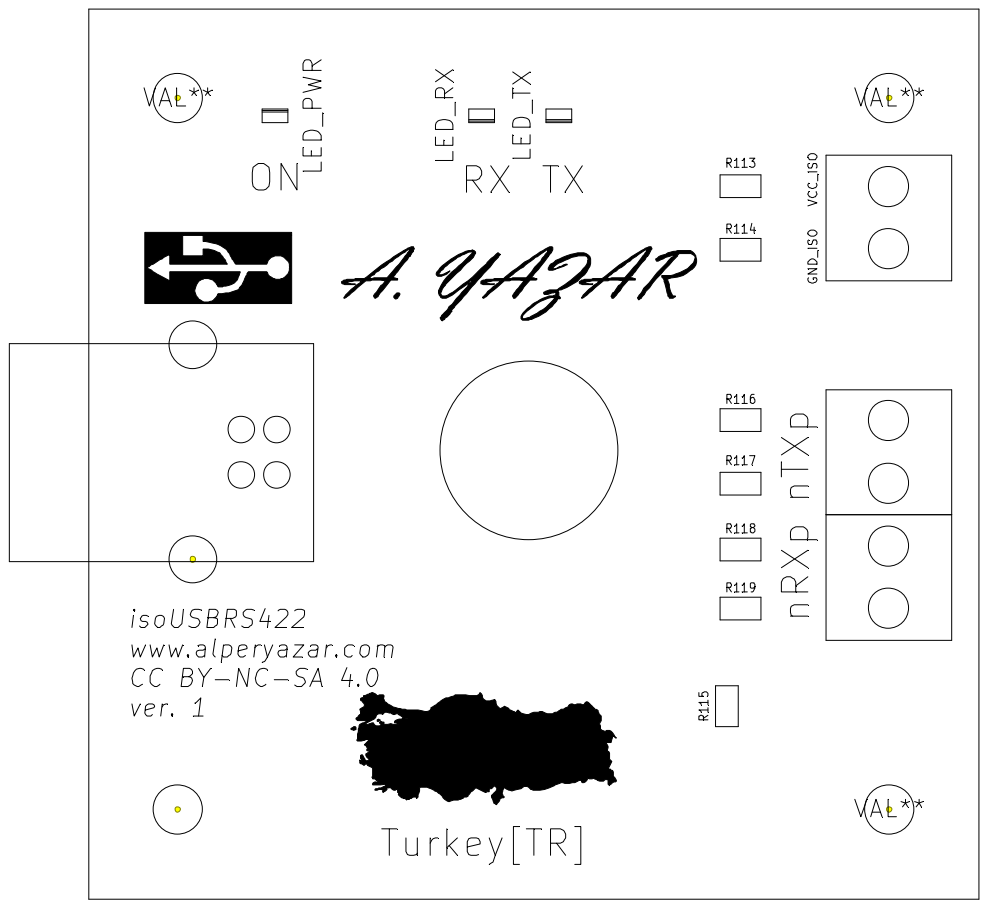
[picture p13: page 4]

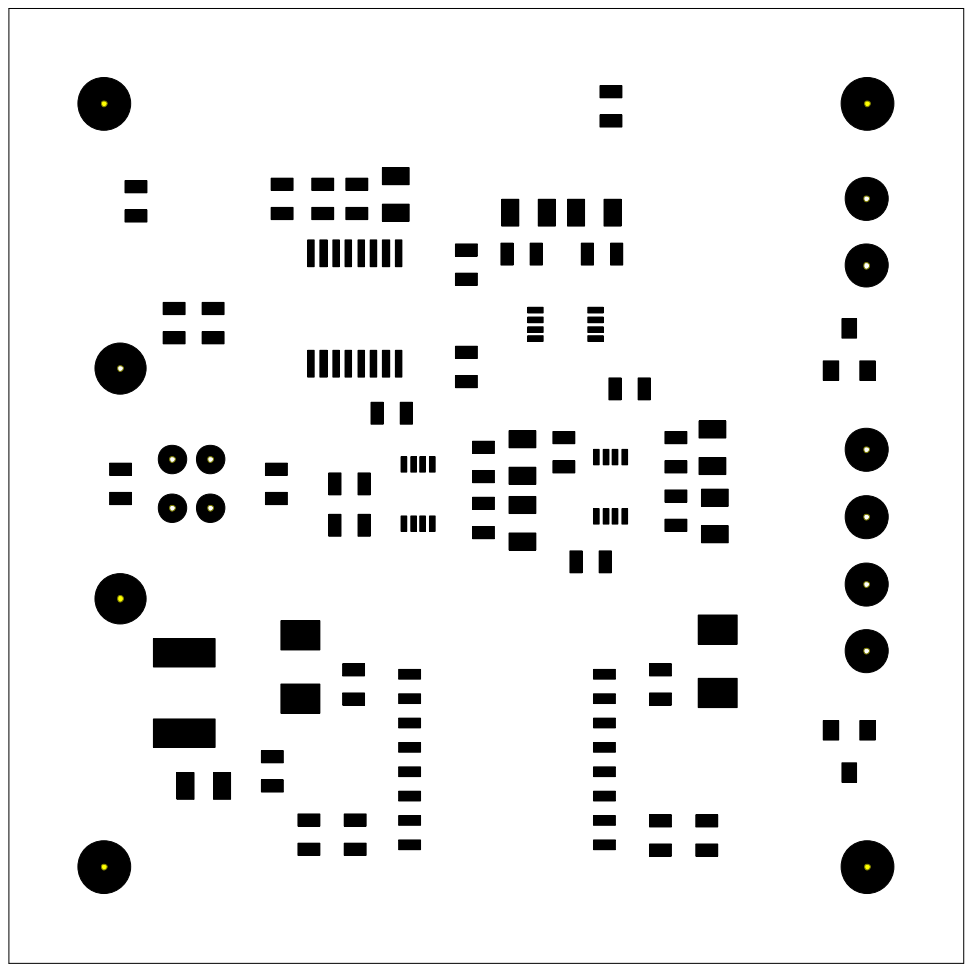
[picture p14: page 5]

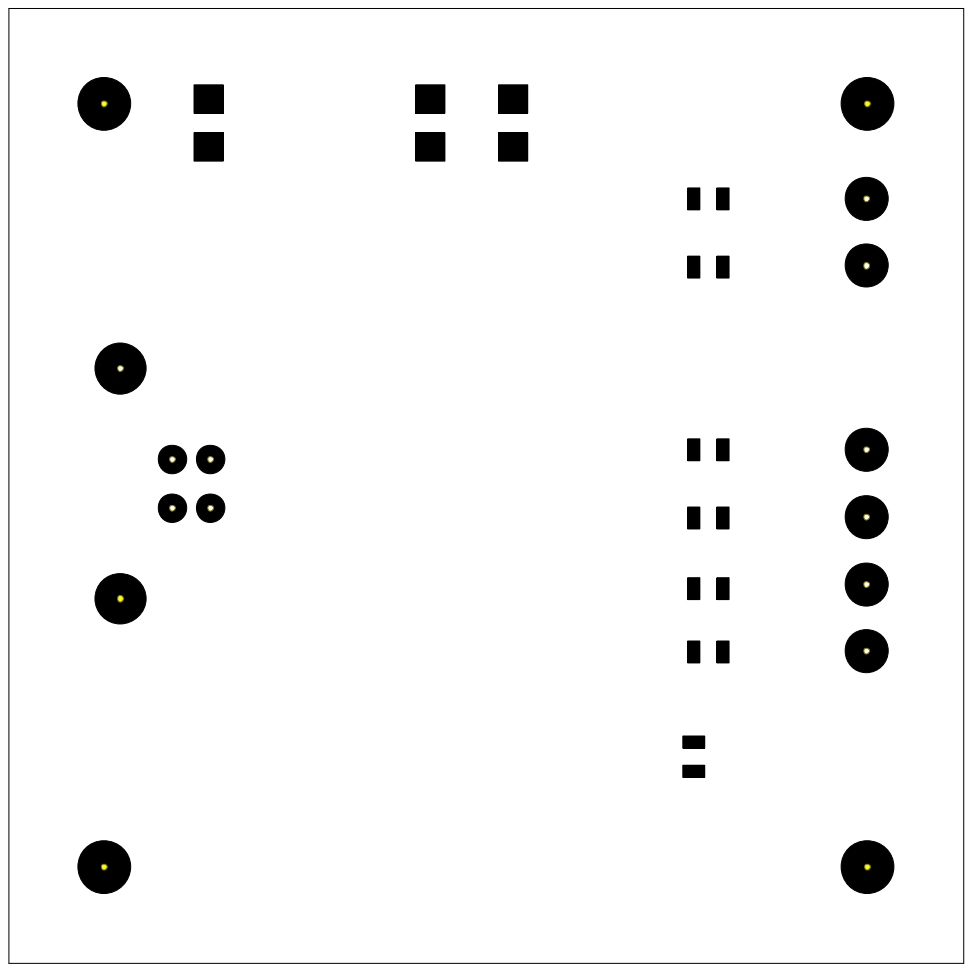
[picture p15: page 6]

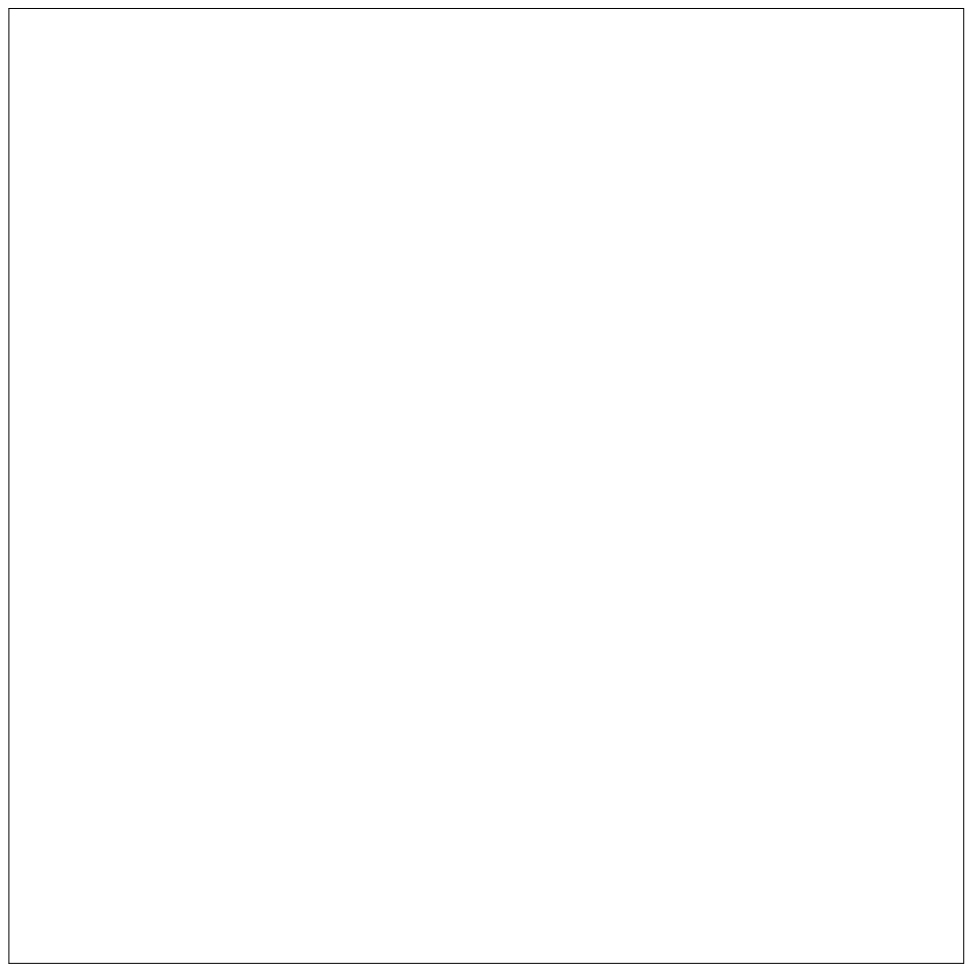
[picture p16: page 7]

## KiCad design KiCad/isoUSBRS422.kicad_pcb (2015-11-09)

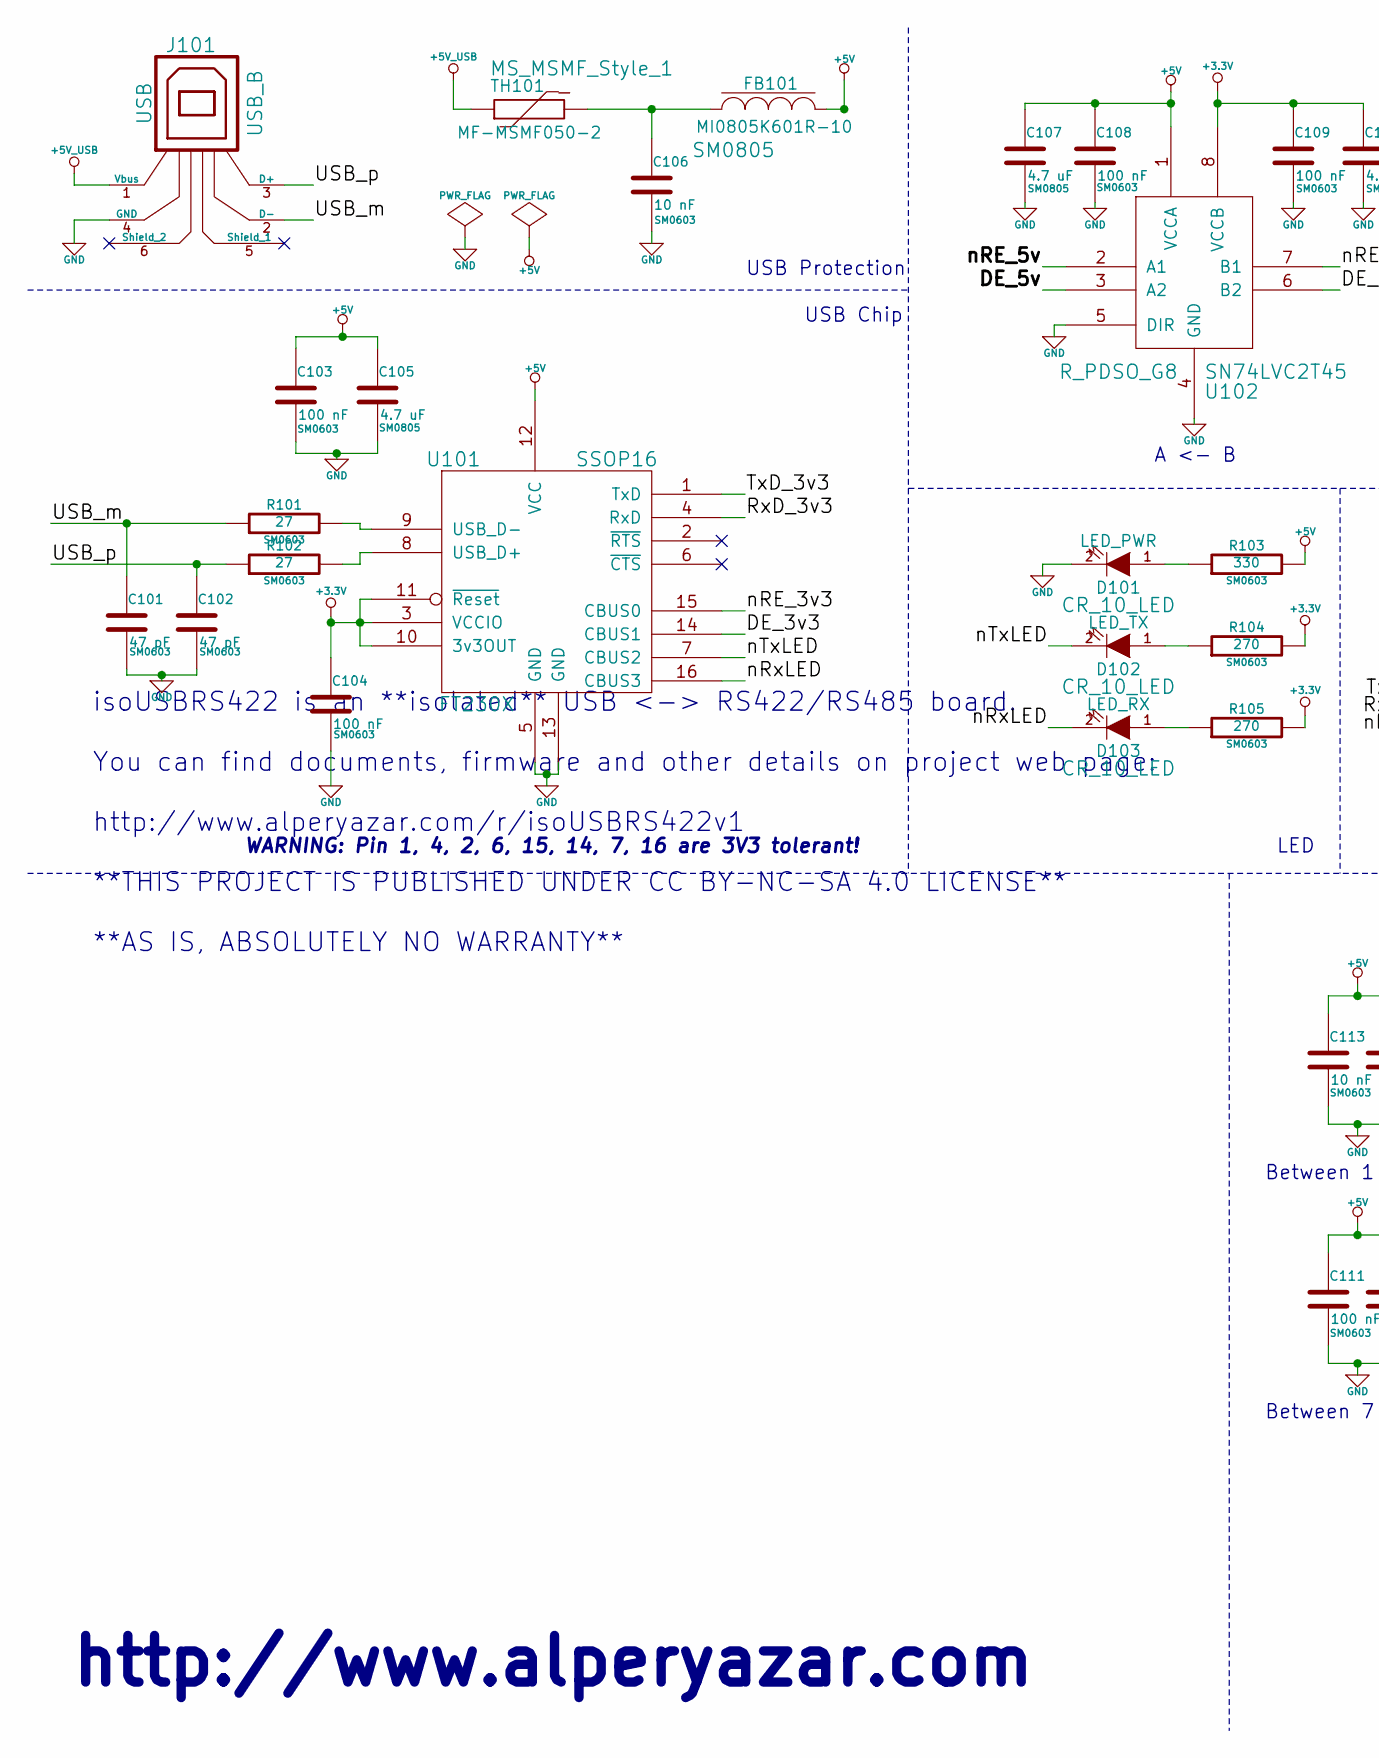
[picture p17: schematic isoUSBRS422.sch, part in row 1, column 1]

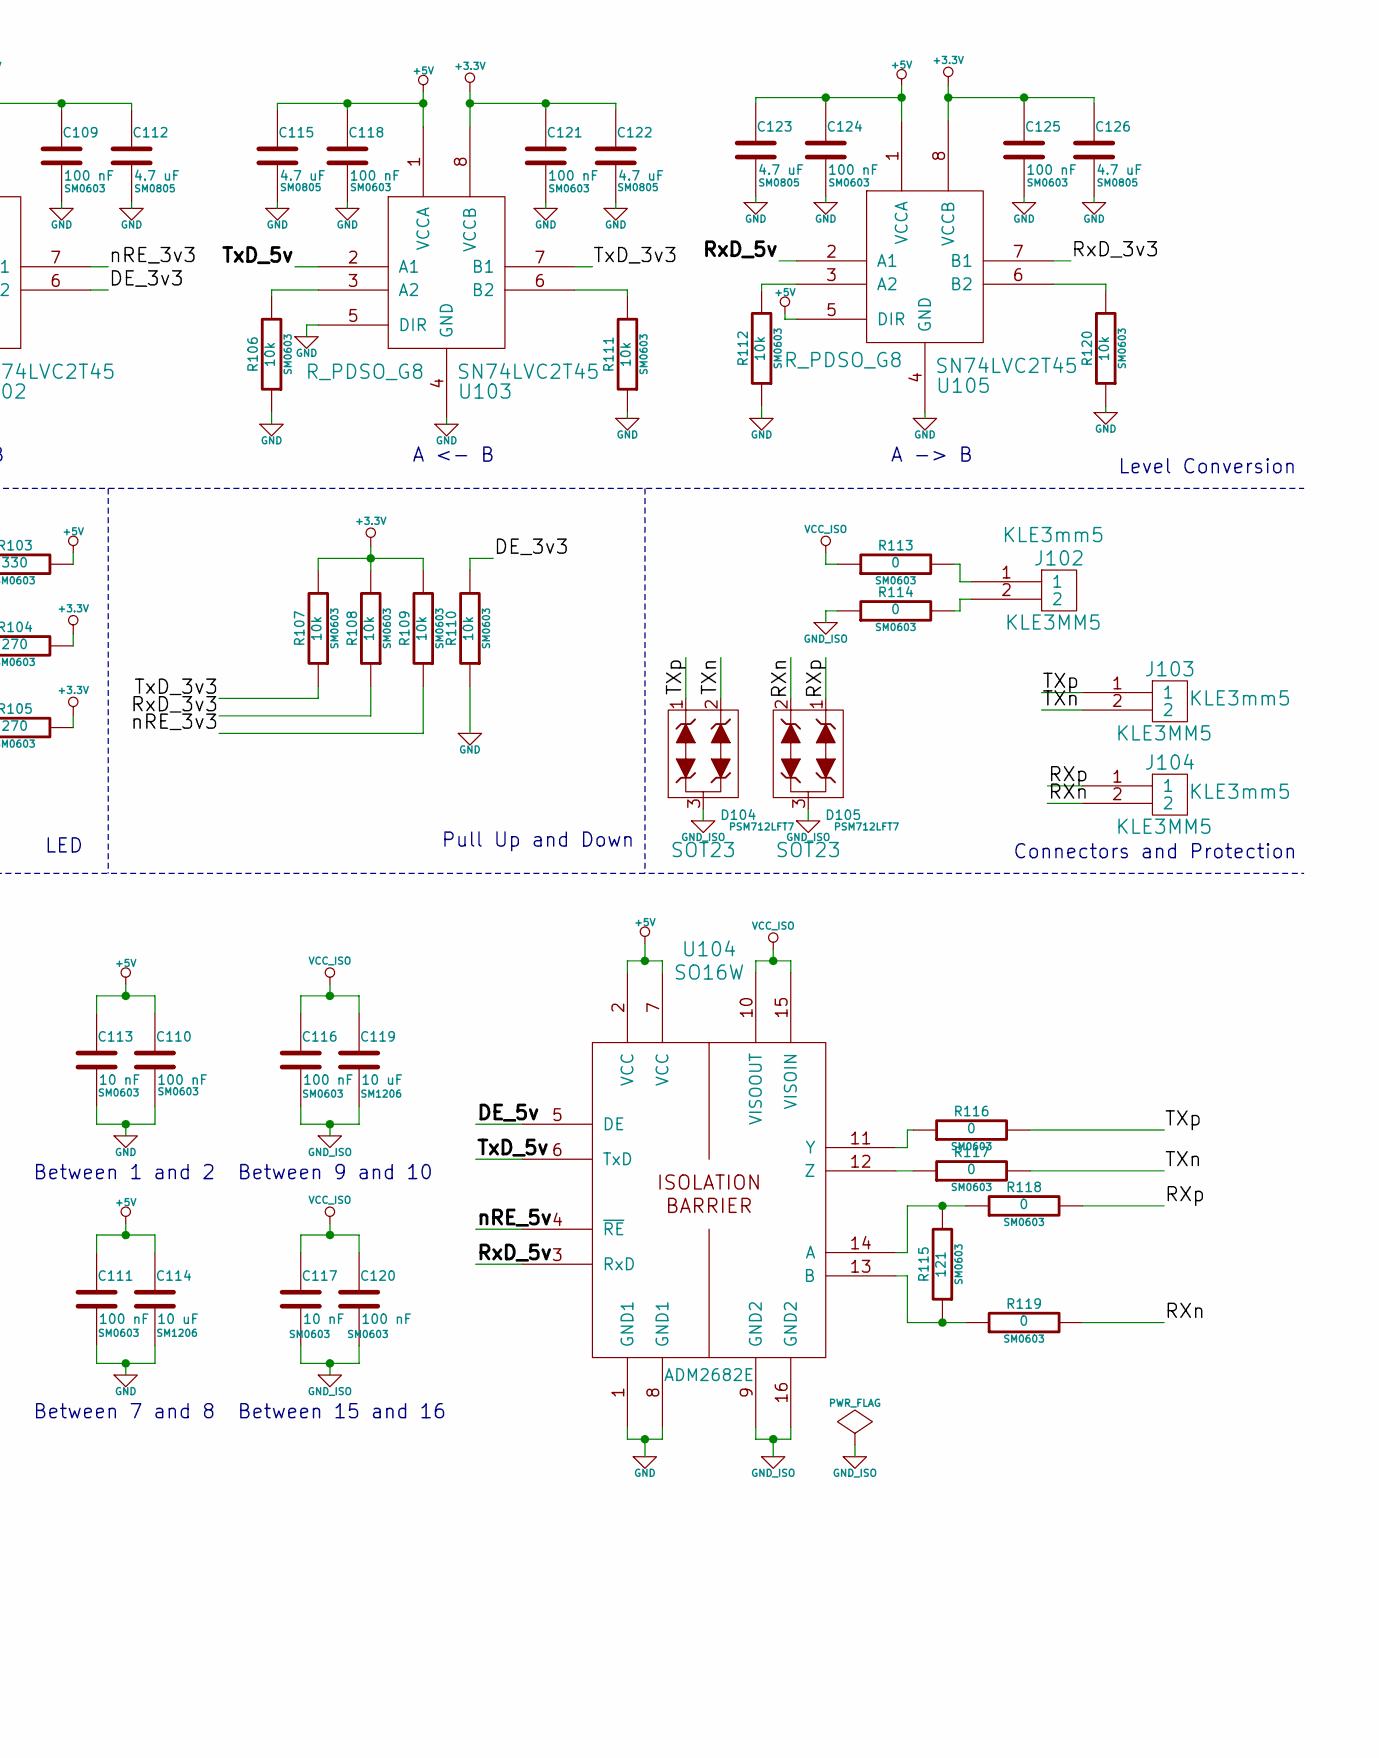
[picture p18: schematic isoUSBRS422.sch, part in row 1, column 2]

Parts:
C101, C102: 47 pF; SM0603
C103, C104, C108, C109, C110, C111, C116, C118, C120, C121, C124, C125: 100 nF; SM0603
C105, C107, C112, C115, C122, C123, C126: 4.7 uF; SM0805
C106, C113, C117: 10 nF; SM0603
C114, C119: 10 uF; SM1206
D101: LED_PWR; CR_10_LED
D102: LED_TX; CR_10_LED
D103: LED_RX; CR_10_LED
D104, D105: PSM712LFT7; SOT23
FB101: MI0805K601R-10; SM0805
J101: USB; USB_B
J102, J103, J104: KLE3MM5; KLE3mm5
R101, R102: 27; SM0603
R103: 330; SM0603
R104, R105: 270; SM0603
R106, R107, R108, R109, R110, R111, R112, R120: 10k; SM0603
R113, R114, R116, R117, R118, R119: 0; SM0603
R115: 121; SM0603
TH101: MF-MSMF050-2; MS_MSMF_Style_1
U101: FT230X; SSOP16
U102, U103, U105: SN74LVC2T45; R_PDSO_G8
U104: ADM2682E; SO16W

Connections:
+3.3V: C104.1, C109.1, C112.1, C121.1, C122.1, C125.1, C126.1, R104.2, R105.2, R107.2, R108.2, R109.2, U101.3 (VCCIO), U101.10 (3v3OUT), U101.11 (~Reset), U102.8 (VCCB), U103.8 (VCCB), U105.8 (VCCB)
+5V: C103.1, C105.1, C107.1, C108.1, C110.1, C111.1, C113.1, C114.1, C115.1, C118.1, C123.1, C124.1, FB101.2, R103.2, U101.12 (VCC), U102.1 (VCCA), U103.1 (VCCA), U104.2 (VCC), U104.7 (VCC), U105.1 (VCCA), U105.5 (DIR)
+5V_USB: J101.1 (Vbus), TH101.1
/DE_3v3: R110.2, U101.14 (CBUS1), U102.6 (B2)
/DE_5v: U102.3 (A2), U104.5 (DE)
/RXn: D105.2, J104.2, R119.2
/RXp: D105.1, J104.1, R118.2
/RxD_3v3: R108.1, U101.4 (RxD), U105.7 (B1)
/RxD_5v: U104.3 (RxD), U105.2 (A1)
/TXn: D104.2, J103.2, R117.2
/TXp: D104.1, J103.1, R116.2
/TxD_3v3: R107.1, U101.1 (TxD), U103.7 (B1)
/TxD_5v: U103.2 (A1), U104.6 (TxD)
/USB_m: C101.1, J101.2 (D-), R101.1
/USB_p: C102.1, J101.3 (D+), R102.1
/nRE_3v3: R109.1, U101.15 (CBUS0), U102.7 (B1)
/nRE_5v: U102.2 (A1), U104.4 (~RE)
/nRxLED: D103.2 (K), U101.16 (CBUS3)
/nTxLED: D102.2 (K), U101.7 (CBUS2)
GND: C101.2, C102.2, C103.2, C104.2, C105.2, C106.2, C107.2, C108.2, C109.2, C110.2, C111.2, C112.2, C113.2, C114.2, C115.2, C118.2, C121.2, C122.2, C123.2, C124.2, C125.2, C126.2, D101.2 (K), J101.4 (GND), R106.1, R110.1, R111.1, R112.1, R120.1, U101.5 (GND), U101.13 (GND), U102.4 (GND), U102.5 (DIR), U103.4 (GND), U103.5 (DIR), U104.1 (GND1), U104.8 (GND1), U105.4 (GND)
GND_ISO: C116.2, C117.2, C119.2, C120.2, D104.3, D105.3, R114.1, U104.9 (GND2), U104.16 (GND2)
unnamed: R106.2, U103.3 (A2)
unnamed: R111.2, U103.6 (B2)
unnamed: R112.2, U105.3 (A2)
unnamed: R120.2, U105.6 (B2)
unnamed: D101.1 (A), R103.1
unnamed: D102.1 (A), R104.1
unnamed: D103.1 (A), R105.1
unnamed: R102.2, U101.8 (USB_D+)
unnamed: R101.2, U101.9 (USB_D-)
unnamed: J102.2, R114.2
unnamed: J102.1, R113.2
unnamed: R117.1, U104.12 (Z)
unnamed: R116.1, U104.11 (Y)
unnamed: R115.1, R119.1, U104.13 (B)
unnamed: R115.2, R118.1, U104.14 (A)
unnamed: C106.1, FB101.1, TH101.2
VCC_ISO: C116.1, C117.1, C119.1, C120.1, R113.1, U104.10 (VISOOUT), U104.15 (VISOIN)

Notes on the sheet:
Between 1 and 2
Between 15 and 16
Between 9 and 10
Between 7 and 8
http://www.alperyazar.com
WARNING: Pin 1, 4, 2, 6, 15, 14, 7, 16 are 3V3 tolerant!
USB Protection
USB Chip
Level Conversion
LED
Pull Up and Down
Connectors and Protection
A <- B
A -> B
isoUSBRS422 is an **isolated** USB <-> RS422/RS485 board. You can find documents, firmware and other details on project web page: http://www.alperyazar.com/r/isoUSBRS422v1 **THIS PROJECT IS PUBLISHED UNDER CC BY-NC-SA 4.0 LICENSE** **AS IS, ABSOLUTELY NO WARRANTY**

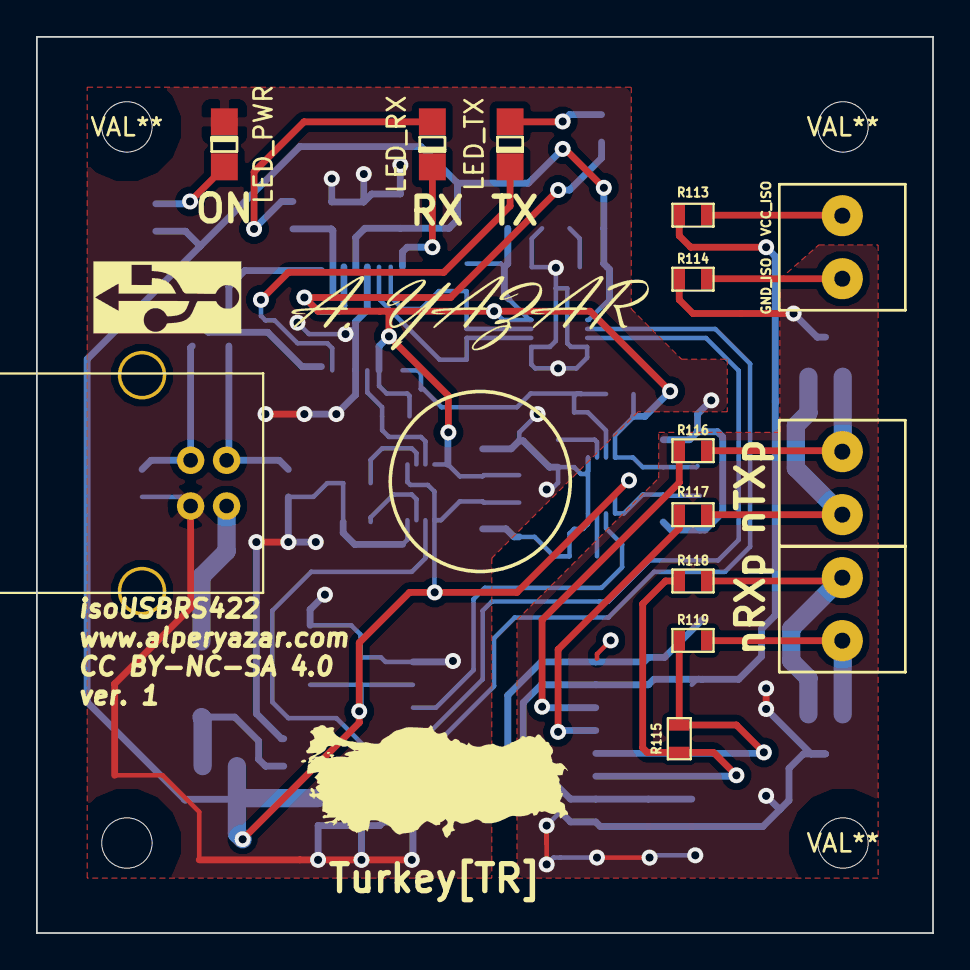
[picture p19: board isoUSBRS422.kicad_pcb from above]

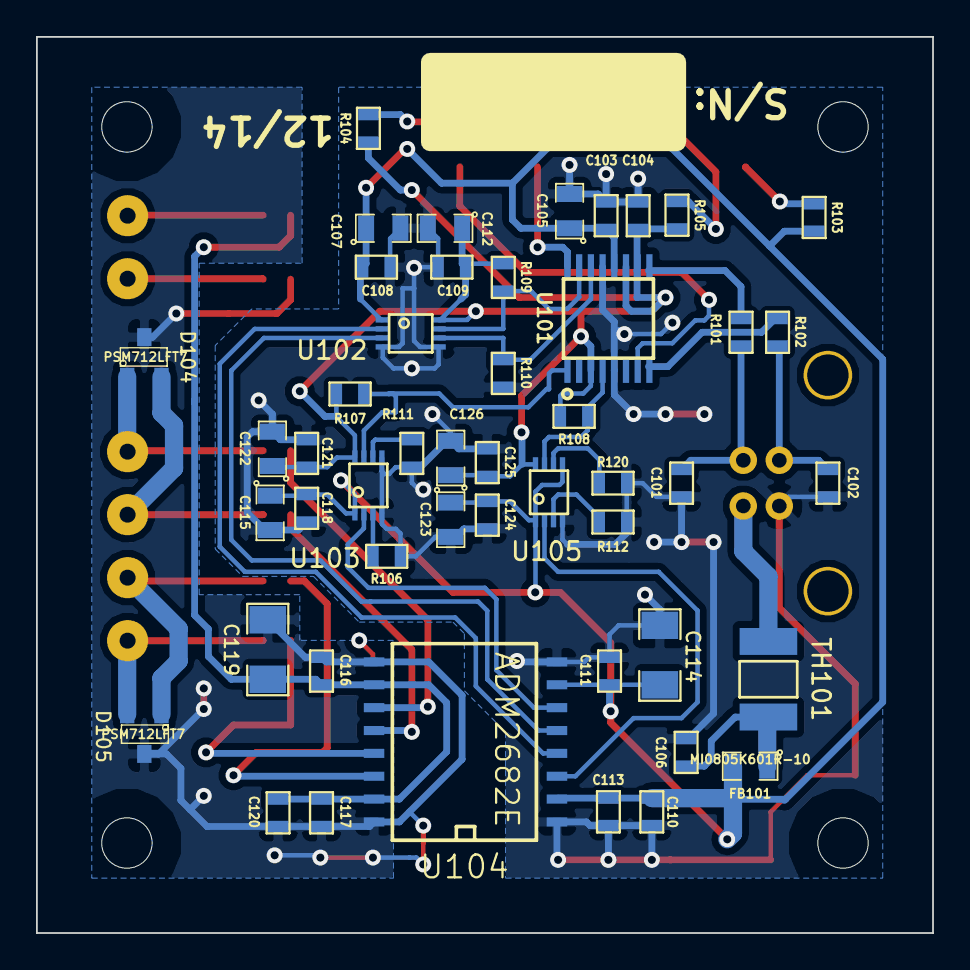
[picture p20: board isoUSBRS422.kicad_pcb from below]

Board: 2 copper layers, 49.8 x 49.8 mm, 69 parts (48 on the bottom side), 38 nets.

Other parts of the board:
Hole_2mm8_6mm0, Hole_2mm8_6mm0#2, Hole_2mm8_6mm0#3, Hole_2mm8_6mm0#4: VAL**; Hole_2mm8_6mm0
VAL: REF; ayazar
VAL#2: REF; usb_logo_4mm
VAL#3: REF; turkiye_15mm
